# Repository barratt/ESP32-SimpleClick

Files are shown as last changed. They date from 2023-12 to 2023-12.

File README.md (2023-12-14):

I was looking for a simple small ESP32 that could be used as a desktop or portable IOT button.

The rationale behind not using Zigbee or BLE was simplicity & cost for the end user. It can either be connected via type C to a PC or through WiFi using a battery.

If you're looking to build one, I sent everything in the gerbers folder to JLCPCB and paid for SMD assembly. In total I paid £20 for 5 boards, so £4 per button overall. The button and LED needs soldering by hand, however since they're the biggest components, this is easy.

You can see a full bom in the gerbers folder.

Some issues that need addressing:

- The capacitors on the 3.3v line feeding the ESP are not connected. (I fixed this after using a blob of solder)
- The battery charging module does not output sufficient current with no battery connected - which means the LDO regulator does not get enough power to supply the ESP32.
This can be solved by adding 2 low drop diodes to the schematic, or just removing the battery charging and soldering the LDO input to 5v (like I did in a bodge).
- The RGB LED connector is untested - I didn't need this 
- There are no jumpers / test points to put the ESP into programming mode. As such you'll need to solder leads to the ESP directly and remove them after flashing, as shown in the images below.

It's unlikely I'll come back to the project as it solves my requirements, so if you do fix any of the above please submit a pull request, otherwise do what you like with this!

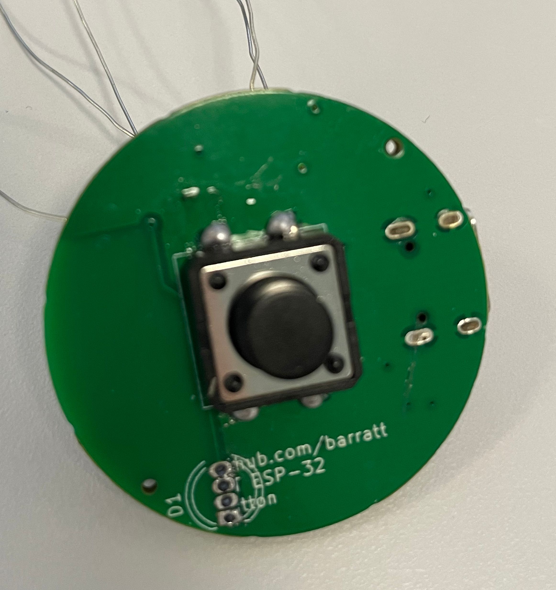
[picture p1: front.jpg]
front

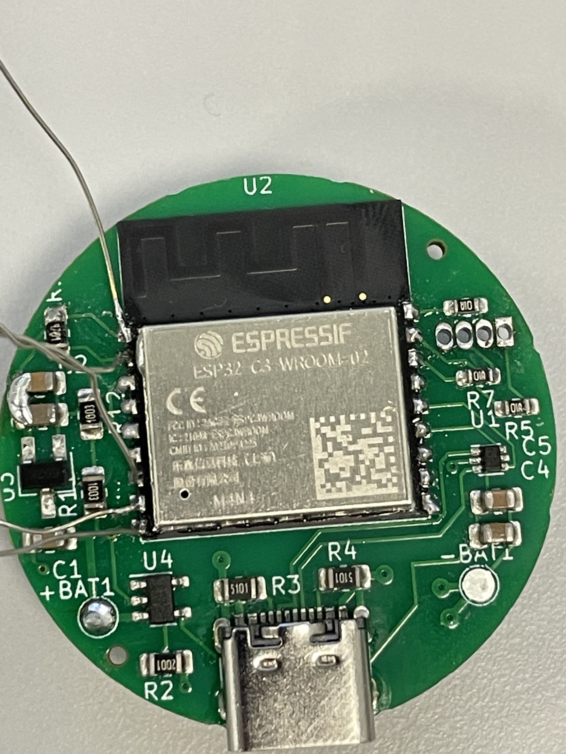
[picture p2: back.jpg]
back


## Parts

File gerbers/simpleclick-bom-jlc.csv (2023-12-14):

Comment | Designator | Footprint | LCSC
4u7F | C1, C3, C4, C5 | Capacitor_SMD:C_0805_2012Metric_Pad1.18x1.45mm_HandSolder | C1779
10uF | C2 | Capacitor_SMD:C_0805_2012Metric_Pad1.18x1.45mm_HandSolder | C15850
BLM21PG221SZ1D | FB1 | Resistor_SMD:R_0805_2012Metric_Pad1.20x1.40mm_HandSolder | C437411
SMD USB TYPE C | J1 | Connector_USB:USB_C_Receptacle_G-Switch_GT-USB-7010ASV | C2927302
4k7 | R1 | Resistor_SMD:R_0805_2012Metric_Pad1.20x1.40mm_HandSolder | C17673
2k | R2 | Resistor_SMD:R_0805_2012Metric_Pad1.20x1.40mm_HandSolder | C17604
5k1 | R3, R4 | Resistor_SMD:R_0805_2012Metric_Pad1.20x1.40mm_HandSolder | C27834
100R | R5, R6, R7 | Resistor_SMD:R_0805_2012Metric_Pad1.20x1.40mm_HandSolder | C22775
100k | R11, R12 | Resistor_SMD:R_0805_2012Metric_Pad1.20x1.40mm_HandSolder | C149504
USBLC6-2P6 | U1 | Package_TO_SOT_SMD:SOT-666 | C2827693
ESP32-C3-WROOM-2 | U2 | PCM_Espressif:ESP32-C3-WROOM-02 | C2934560
SK6206P332MR | U3 | Package_TO_SOT_SMD:SC-59_Handsoldering | C962716
MCP73831-2-OT | U4 | Package_TO_SOT_SMD:SOT-23-5 | C424093

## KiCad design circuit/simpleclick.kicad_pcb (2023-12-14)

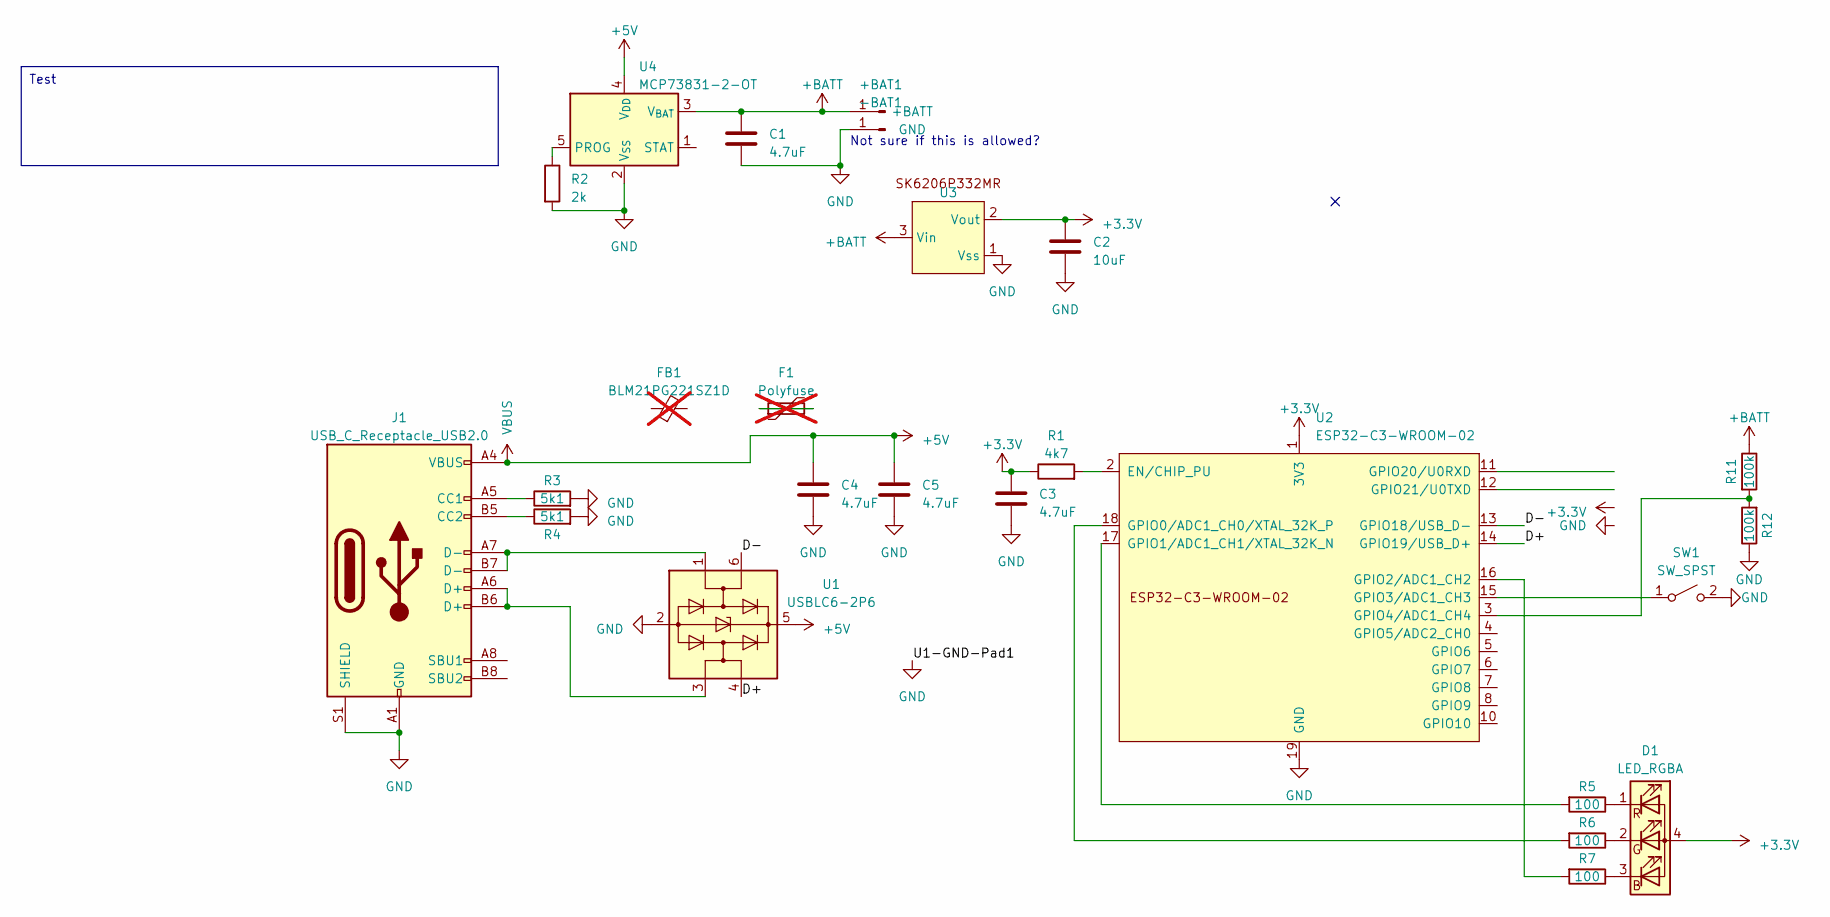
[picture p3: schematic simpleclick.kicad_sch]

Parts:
+BAT1: +BATT; TestPoint_Pad_D2.0mm
-BAT1: GND; TestPoint_Pad_D2.0mm
C1, C3, C4, C5: 4.7uF; C_0805_2012Metric_Pad1.18x1.45mm_HandSolder
C2: 10uF; C_0805_2012Metric_Pad1.18x1.45mm_HandSolder
D1: LED_RGBA; LED_D5.0mm-4_RGB
F1: Polyfuse; R_0805_2012Metric_Pad1.20x1.40mm_HandSolder; not fitted
FB1: BLM21PG221SZ1D; R_0805_2012Metric_Pad1.20x1.40mm_HandSolder; not fitted
J1: USB_C_Receptacle_USB2.0; USB_C_Receptacle_G-Switch_GT-USB-7010ASV
R1: 4k7; R_0805_2012Metric_Pad1.20x1.40mm_HandSolder
R2: 2k; R_0805_2012Metric_Pad1.20x1.40mm_HandSolder
R3, R4: 5k1; R_0805_2012Metric_Pad1.20x1.40mm_HandSolder
R5, R6, R7: 100; R_0603_1608Metric_Pad0.98x0.95mm_HandSolder
R11, R12: 100k; R_0805_2012Metric_Pad1.20x1.40mm_HandSolder
SW1: SW_SPST; tact12x12
U1: USBLC6-2P6; SOT-666
U2: ESP32-C3-WROOM-02
U3: SC-59_Handsoldering
U4: MCP73831-2-OT; SOT-23-5

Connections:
+3.3V: C2.1, C3.1, D1.4 (A), R1.1, U2.1 (3V3), U3.2 (Vout)
+5V: C4.1, C5.1, J1.A4 (VBUS), J1.A9 (VBUS), J1.B4 (VBUS), J1.B9 (VBUS), U1.5 (VBUS), U4.4 (V_{DD})
+BATT: +BAT1.1, C1.1, R11.1, U3.3 (Vin), U4.3 (V_{BAT})
/D+: U1.4 (I/O2), U2.14 (GPIO19/USB_D+)
/D-: U1.6 (I/O1), U2.13 (GPIO18/USB_D-)
GND: -BAT1.1, C1.2, C2.2, C3.2, C4.2, C5.2, J1.A1 (GND), J1.A12 (GND), J1.B1 (GND), J1.B12 (GND), J1.S1 (SHIELD), R2.2, R3.2, R4.2, R12.1, SW1.2 (B), U1.2 (GND), U2.9 (GND), U2.19 (GND), U3.1 (Vss), U4.2 (V_{SS})
unnamed: D1.3 (BK), R7.1
unnamed: D1.2 (GK), R6.1
unnamed: D1.1 (RK), R5.1
unnamed: F1.1, F1.2
unnamed: J1.A5 (CC1), R3.1
unnamed: J1.B5 (CC2), R4.1
unnamed: J1.A6 (D+), J1.B6 (D+), U1.3 (I/O2)
unnamed: J1.A7 (D-), J1.B7 (D-), U1.1 (I/O1)
unnamed: SW1.1 (A), U2.15 (GPIO3/ADC1_CH3)
unnamed: R1.2, U2.2 (EN/CHIP_PU)
unnamed: R6.2, U2.18 (GPIO0/ADC1_CH0/XTAL_32K_P)
unnamed: R5.2, U2.17 (GPIO1/ADC1_CH1/XTAL_32K_N)
unnamed: R7.2, U2.16 (GPIO2/ADC1_CH2)
unnamed: R11.2, R12.2, U2.3 (GPIO4/ADC1_CH4)
unnamed: R2.1, U4.5 (PROG)

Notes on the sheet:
Test
Not sure if this is allowed?

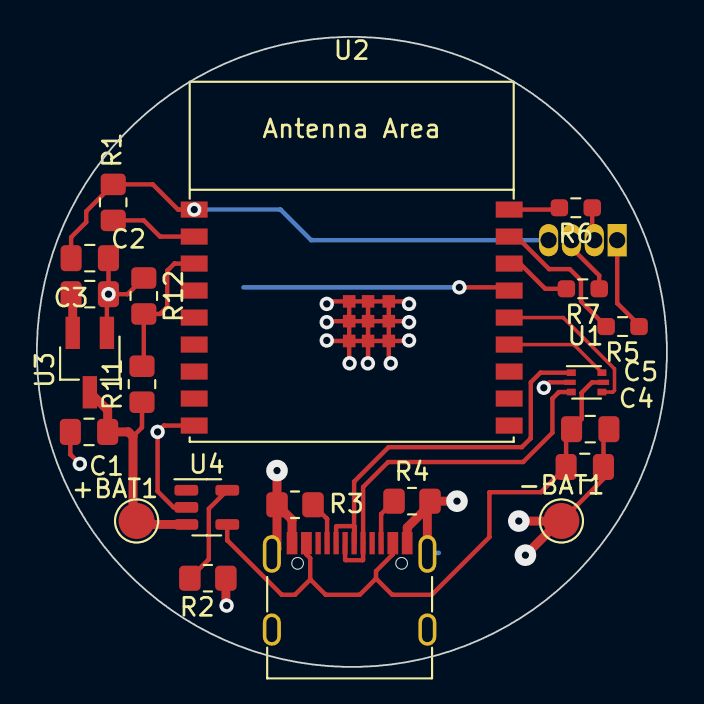
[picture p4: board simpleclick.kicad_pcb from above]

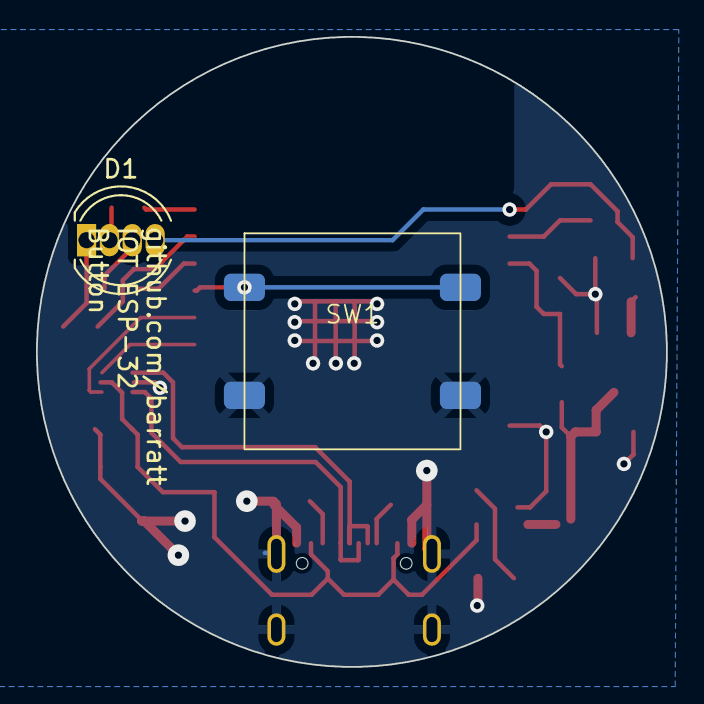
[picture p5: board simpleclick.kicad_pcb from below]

Board: 2 copper layers, 35.0 x 35.0 mm, 23 parts (2 on the bottom side), 20 nets.
